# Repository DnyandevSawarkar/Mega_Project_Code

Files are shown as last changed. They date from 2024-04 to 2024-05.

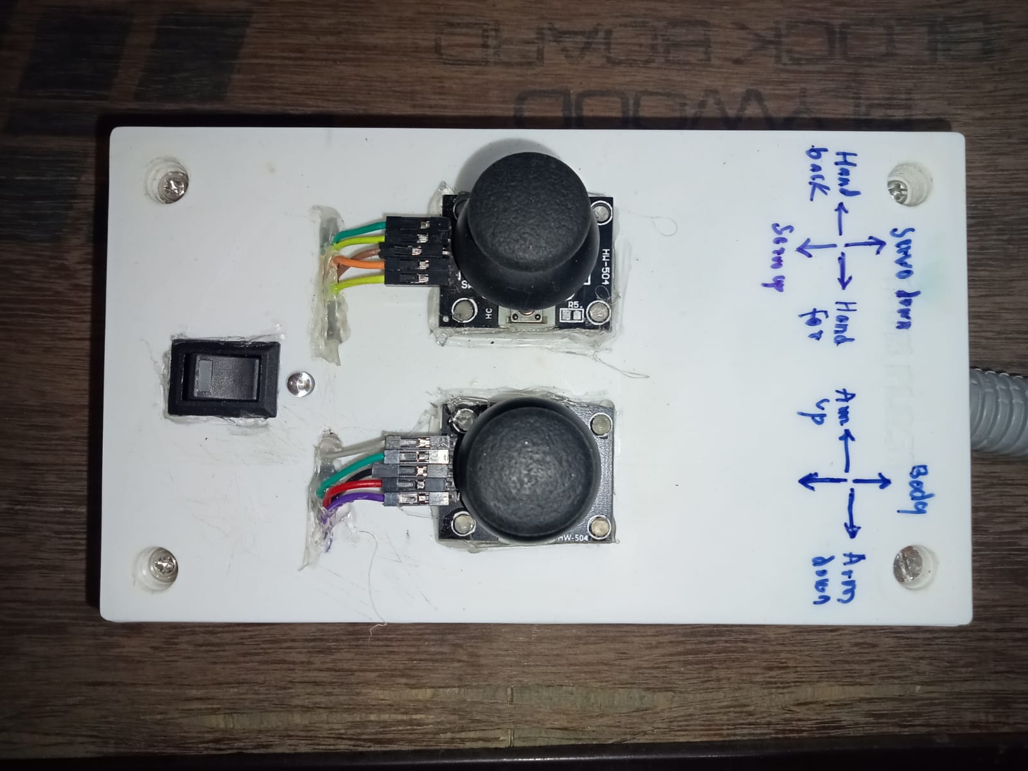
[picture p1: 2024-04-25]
Images/control_unit.jpg

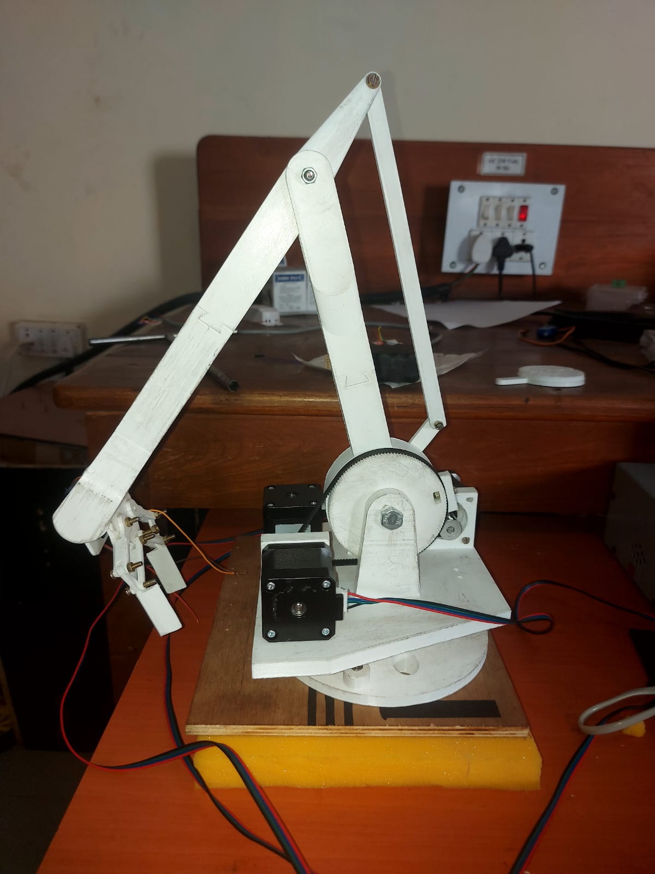
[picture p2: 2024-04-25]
Images/arm_right.jpg

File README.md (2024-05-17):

# Mega_Project_Code
# Name : Design and Development of Robotic ARM for Educational Purpose.
## Description
* Creating Platforms for Student having interest in Robotics or Cording.
* Platform to teach and demonstrate Ladder Coding.
* Controlling Robotic Arm using Joystick's to attract Small Class Student's.
## Information
➥ Application Creator:
 * icon.rc                      : Icon file path container for icon.res.
 * icon.res                     : Icon file for the application.
 * icon256x256.ico              : Icon file
 * Robotic Arm Controller.c     : Main C file of the application.
 * Robotic Arm Controller.exe   : Main executable file of the application.

➥ Backend:
 *    backend.py        : Get  data from the front end and send it to the esp-01 microcontroller.
 *    text.txt          : File that will be read by the esp-01, contains a block controller for the robotic arm.

➥ Body Parts STL:
 * STL Files Body and Gripper parts of the robotic arm.

➥ Frontend:
 *    index.html        : The main page of the website where you can write in an input field what command do you want to execute on the robotic arm.
 *    styles.css        : Stylesheet of the web page.
 *    script.js         : Functions related with the user interface (buttons,blocks,interconnecting link with backend.

➥ Mega Project ESP: 
 *    ESP-01 code to get the data sent by the backend and send it UNO for excutiong.
 *    Control Servo motors of Gripper according UNO feedbacks .
 *    Give feedback to UNO  about the execution status of gripper  movements.

➥ Mega Project UNO: 
 *    Uno Code to execute commands received from ESP.
 *    Controll Stepper Motor of required part.
 *    Send Command to ESP for execution Gripper Movements.
 *    Monitor Joystick and Robotic Arm.

➥ Py_Module_Installer:
 *    req.c            : C code which contains list of python module required for backend.
 *    req.exe          : Excutalbe exe file which will install all the required python module.

## Hardware Configuration
### UNO
* D12  : Joystick 1 Switch
* D11  : Joystick 1 Switch ( Z+ pin of CNC Shield)
* A0   : Joystick 1 Vx
* A1   : Joystick 1 Vy
* A2   : Joystick 2 Vx
* A3   : Joystick 2 Vy
* GND  : Joysticks GND
* 5V   : Joysticks VCC

### NodeMCU
* D4   : Servo 1 Signal (Gripper Body)
* D3   : Servo 2 Signal (Gripper Hands)
* GND  : Servos GND
* 5V   : Servos VCC

### Serial Communication
* UNO RX -> TX ESP
* ESP RX -> TX UNO

### Power Supply
* 230V AC to
   * 12V 5Amp. DC for CNC Shield
   * 9V 1.5Amp. DC for UNO Power Jack
      * 9V to 5V (7805) for NodeMCU Vin

➥ Note : Use separate power source for Joystcks and Servos for proper Working
* Servo 5V from 7805
* Joystick's 5V from CNC Shield 

## How To Run
* Download and Install [Python ](https://www.python.org/downloads/).
* Clone git repository.
* Install all the required python module using req.exe file.
* Power on Roboic Arm Control Unit
* Open Robotic Arm Controller.exe
* Connect System to NodeMCU Wi-Fi 
    * SSID : Robotic_Arm 
    * Password : Robotic_Arm.

## Testing
### 1) Software Application.
* Create Ladder Code to Controll Robotic Arm and Press Submite Button.
* Observe Robotic Arm Movement.

### 2) Hardware Application 
* Controll Robotic Arm by Using Joystick's. 

## Pictures
### Robotic Arm
Final_Arm

arm_right

arm_left

### Pick and Place operation 
pick_place

### Web Dashboard
Web Page

### Control Unit
control_unit

### Block Diagram 
Robotic arm block diagram

### FlowChart
#### Hardware - Joystick Control
joystick

#### Software - Web Dashboard Control
web_flowchart

### Circuit Schematic and PCB Board Connection
#### Schematic
circuit

#### Top Layer
Top_Layer

#### Buttom Layer
Bottom_layer

* Note : Circuit Schematic and PCB Board Connection are only for understanding connection their no need of this PCB CNC Shield get directly attached to UNO and for mounting NodeMCU we can create ZeroPCB based PCB which directly connects to CNC shield and works on external supply obtained from 7805 as an input for servo and NodeMCU

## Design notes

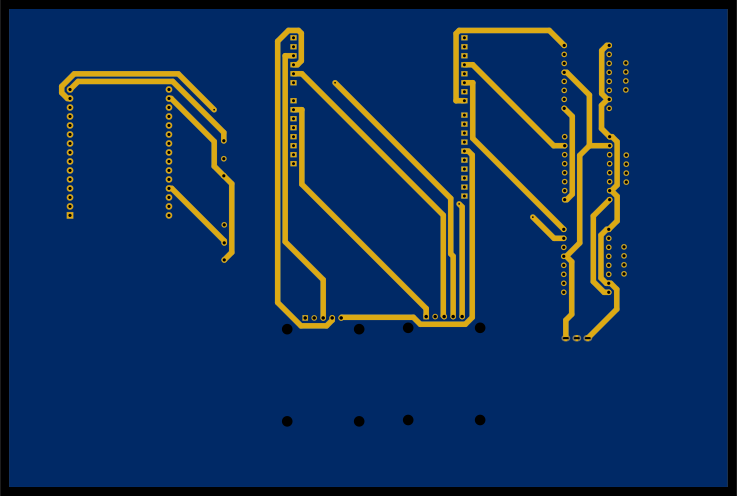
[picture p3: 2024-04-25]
Images/Bottom_layer.png

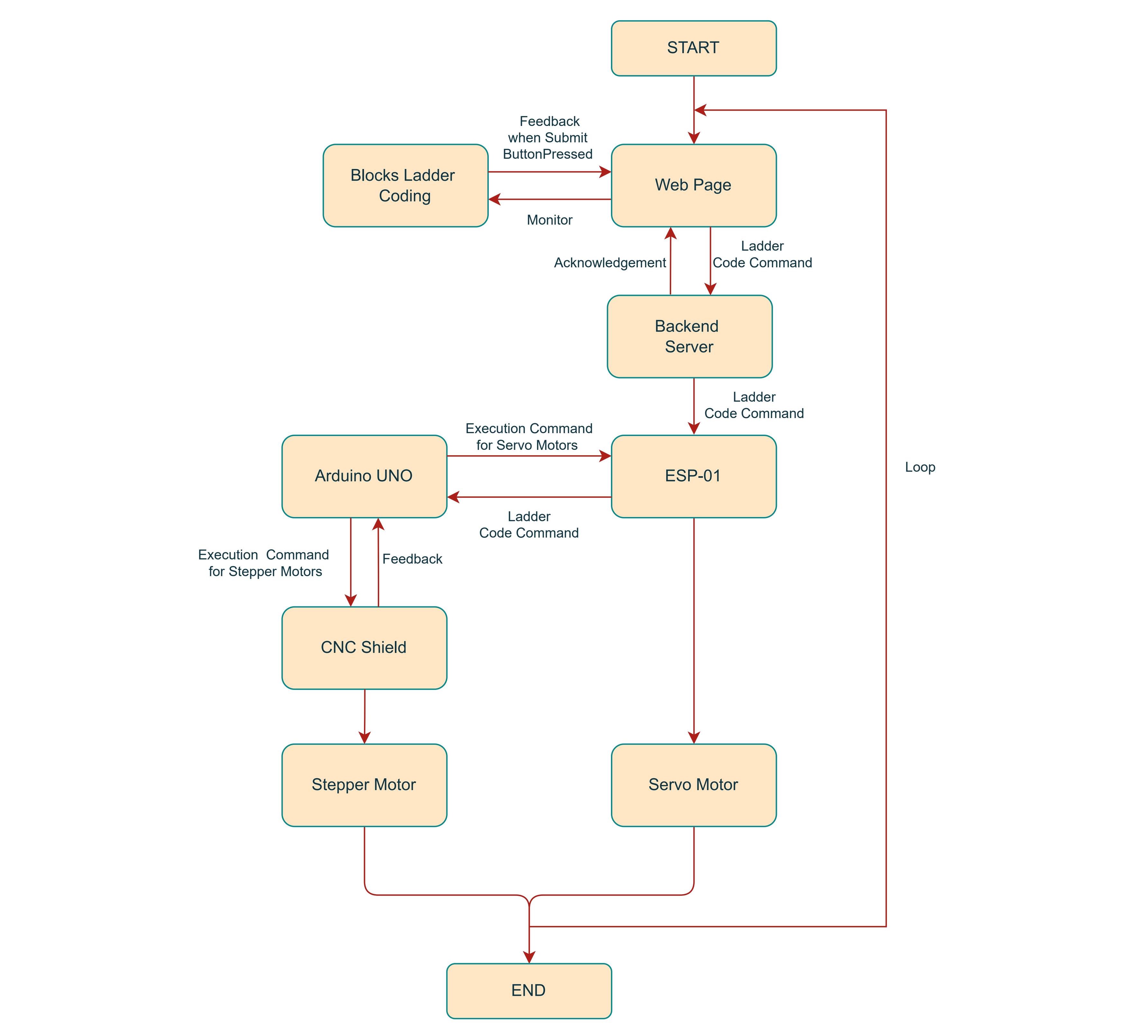
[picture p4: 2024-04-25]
Images/web_flowchart .jpg

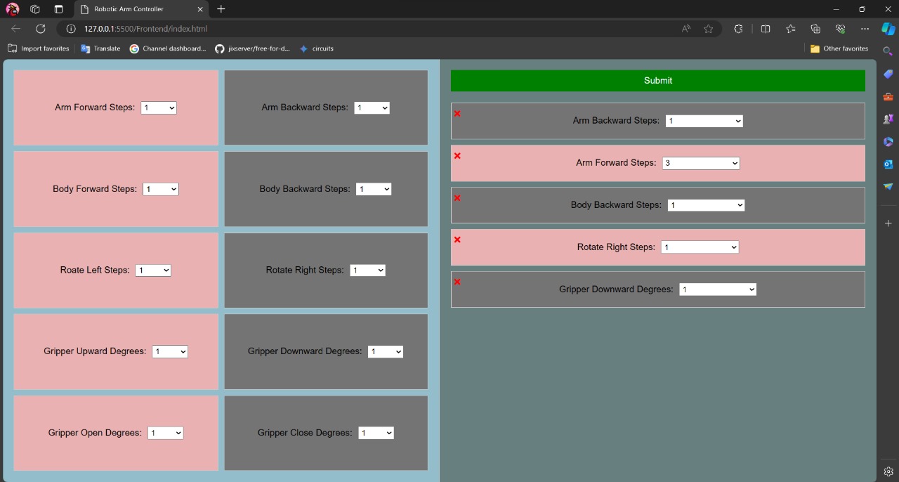
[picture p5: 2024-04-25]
Images/Web Page.jpg

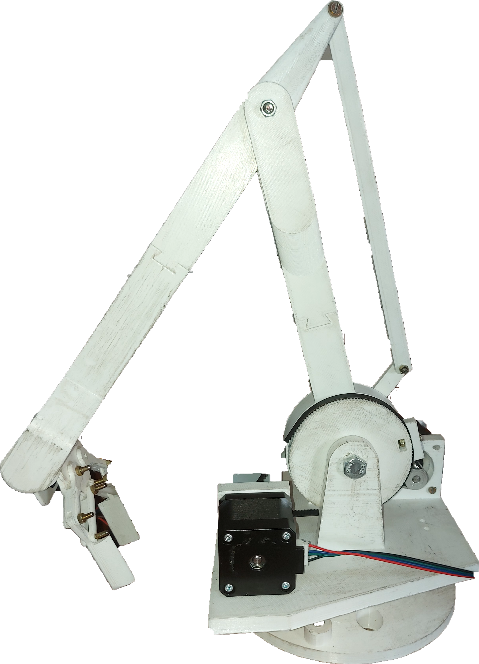
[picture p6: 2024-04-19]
Images/Final_Arm.png

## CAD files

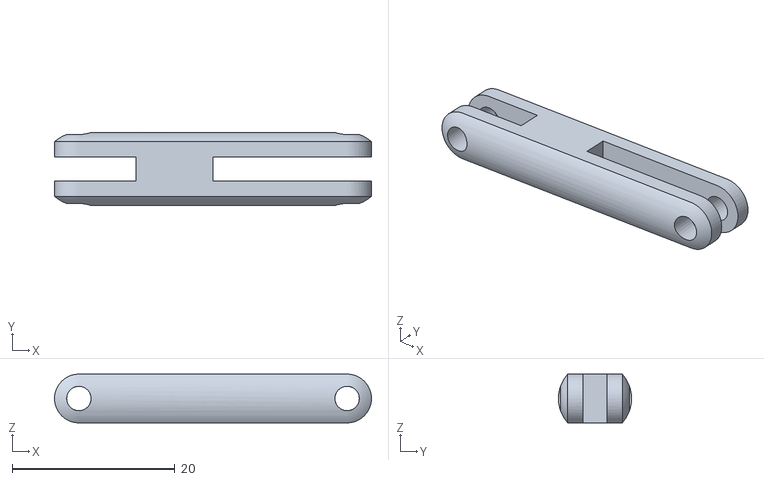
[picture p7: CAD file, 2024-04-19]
Body_Parts_STL/Phalange_medial (R).stl
39.0 x 9.00 x 6.00

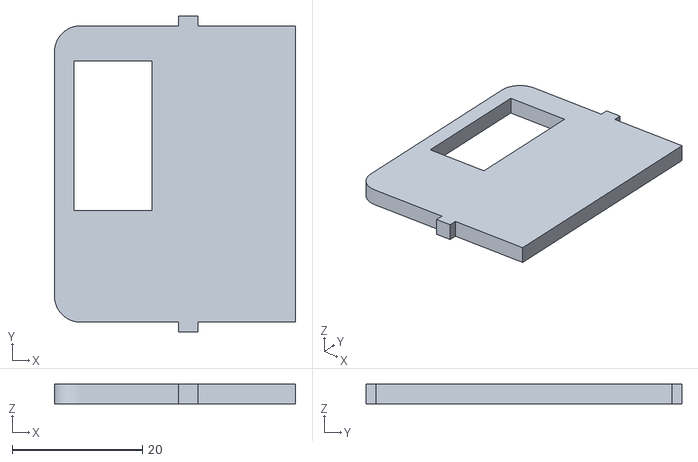
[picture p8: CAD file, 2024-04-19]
Body_Parts_STL/Arm_C1.stl
37.0 x 48.5 x 3.00

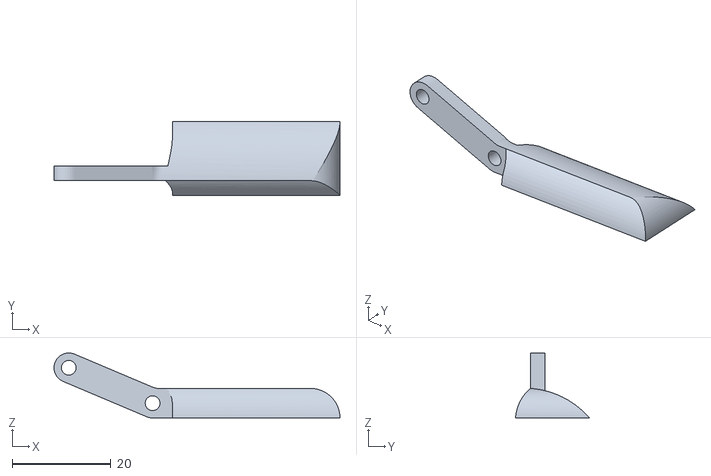
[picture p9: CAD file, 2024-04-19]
Body_Parts_STL/Phalange_distal_L.stl
58.0 x 15.0 x 13.2

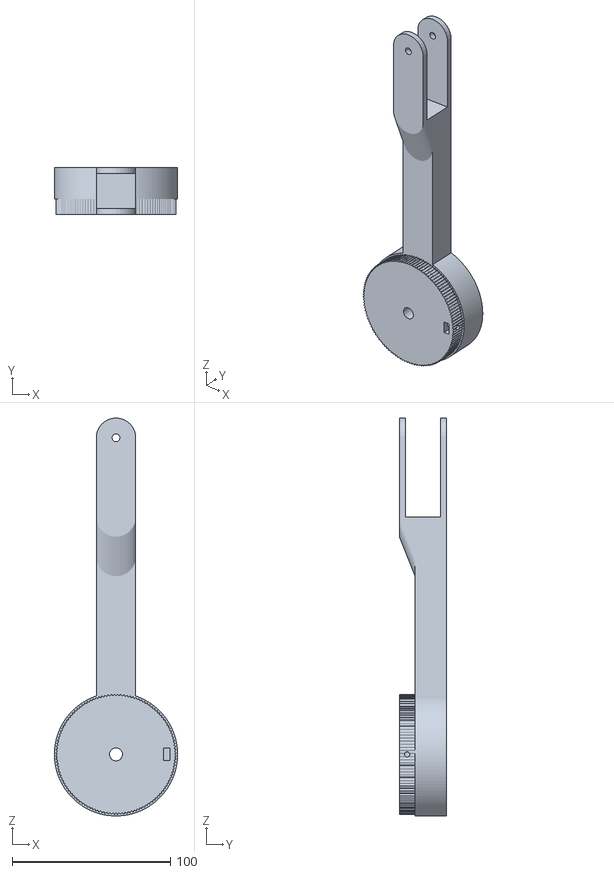
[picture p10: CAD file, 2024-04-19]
Body_Parts_STL/arm_2_with_pully.stl
77.9 x 30.0 x 251.4

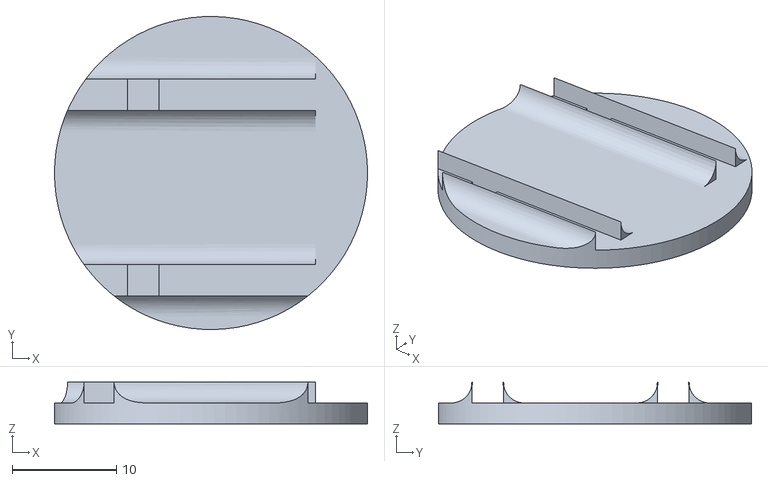
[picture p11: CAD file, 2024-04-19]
Body_Parts_STL/Arm_C3.stl
30.0 x 30.0 x 4.00

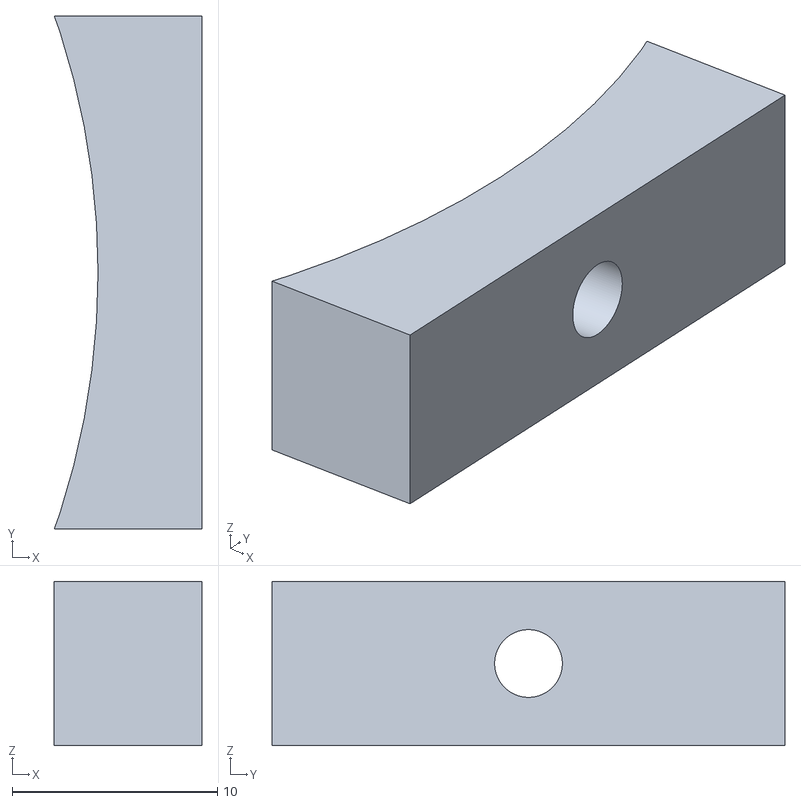
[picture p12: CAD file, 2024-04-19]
Body_Parts_STL/base_2_holder.stl
7.19 x 25.0 x 8.00

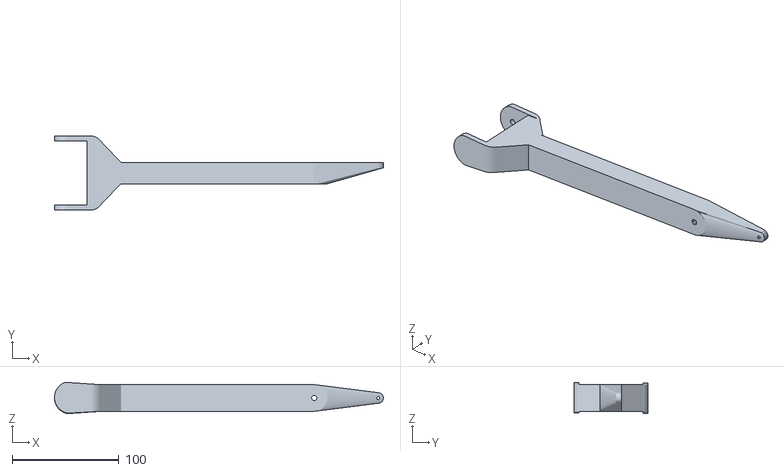
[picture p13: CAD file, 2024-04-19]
Body_Parts_STL/arm_1.stl
308.7 x 69.9 x 29.3

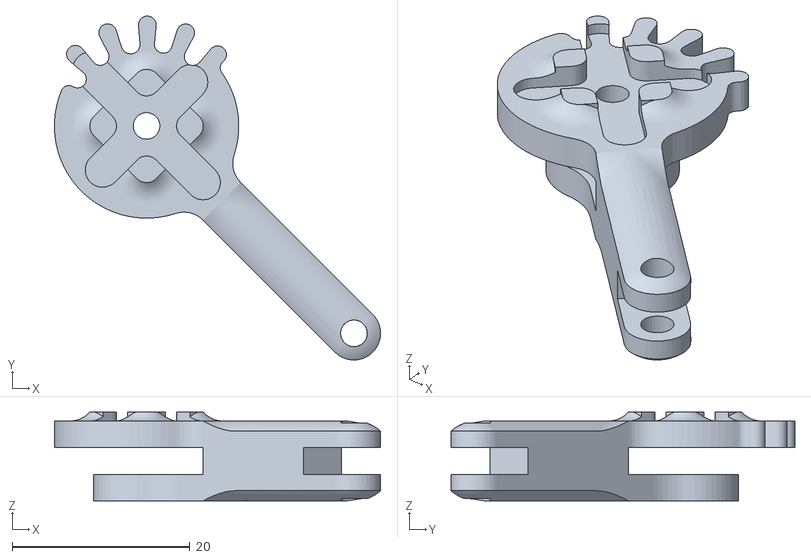
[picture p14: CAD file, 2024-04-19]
Body_Parts_STL/Phalnge_proximal_R.stl
36.7 x 38.7 x 10.0

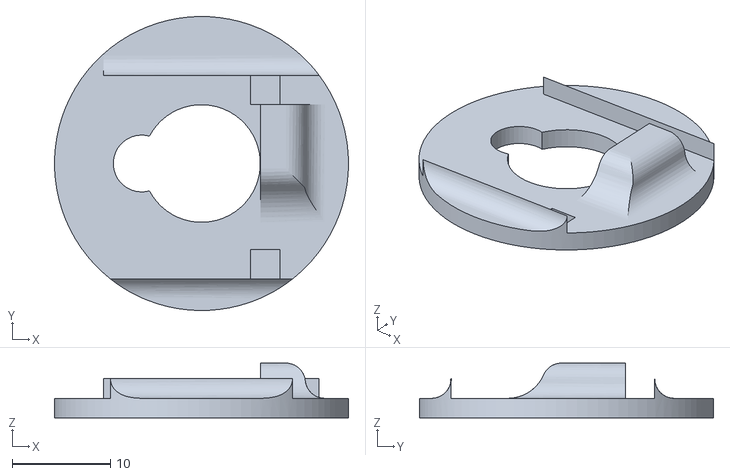
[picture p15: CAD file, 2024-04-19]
Body_Parts_STL/Arm_C4.stl
30.0 x 30.0 x 5.60

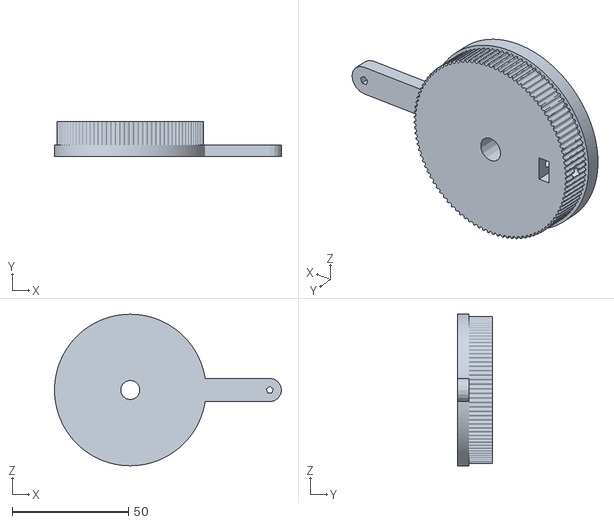
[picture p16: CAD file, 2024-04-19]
Body_Parts_STL/arm_1_pully.stl
97.6 x 15.0 x 65.2

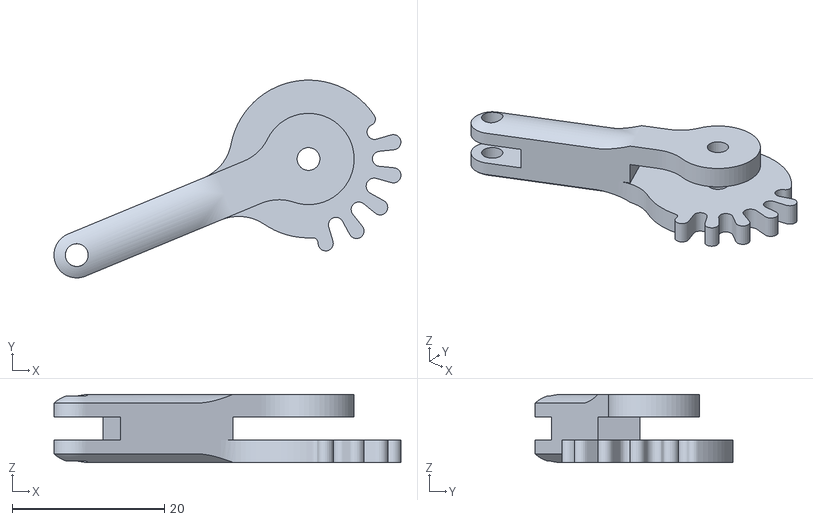
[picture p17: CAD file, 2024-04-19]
Body_Parts_STL/Phalange_proximal_L.stl
45.6 x 26.0 x 9.00

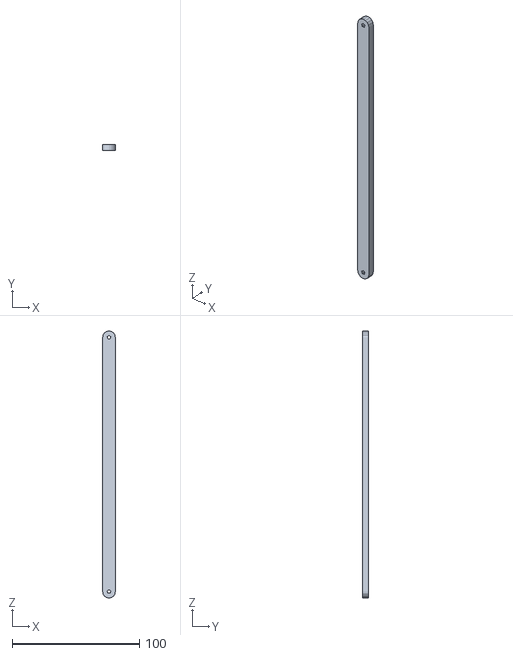
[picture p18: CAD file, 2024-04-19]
Body_Parts_STL/arm_1_rod.stl
10.0 x 5.00 x 210.0

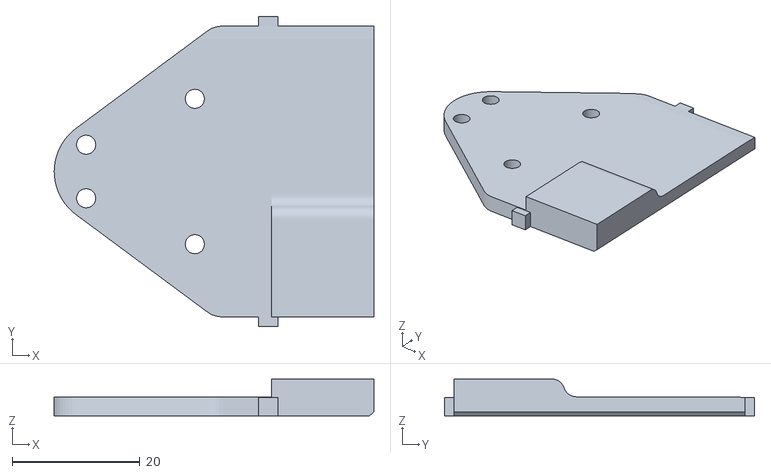
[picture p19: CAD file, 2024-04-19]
Body_Parts_STL/Arm_C2.stl
50.0 x 48.5 x 5.78

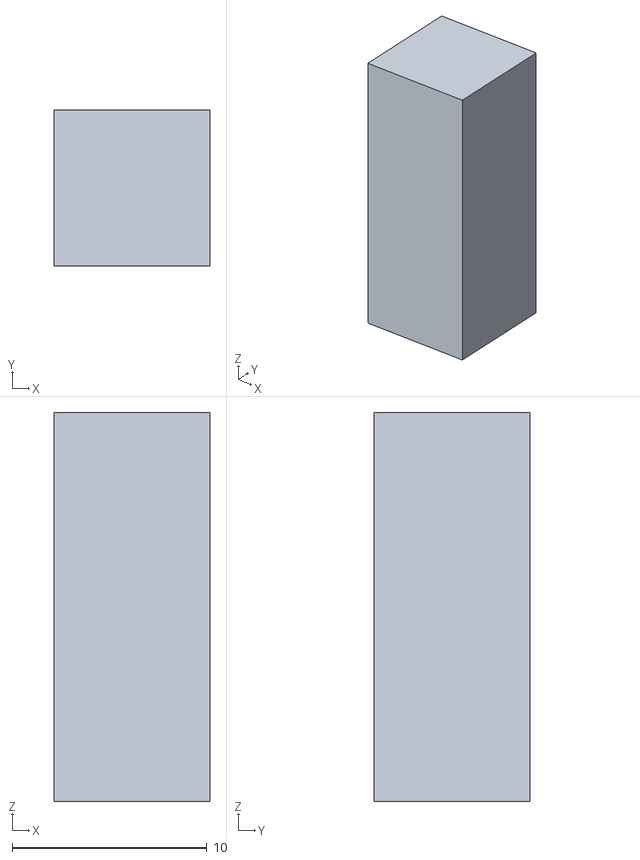
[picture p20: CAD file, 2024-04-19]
Body_Parts_STL/arm_1_holder.stl
8.00 x 8.00 x 20.0

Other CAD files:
Body_Parts_STL/Phalange_distal_R.stl
Body_Parts_STL/arm_2_holder.stl
Body_Parts_STL/base_1.stl
Body_Parts_STL/base_2.stl

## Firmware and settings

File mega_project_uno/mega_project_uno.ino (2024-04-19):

#include <AccelStepper.h>
const int JoyX = A0; // Analog pin of joystick for Body 
const int JoyS = A1; // Analog pin of joystick for Servo
const int JoyY = A2; // Analog pin of joystick for Arm
const int JoyZ = A3; // Analog pin of joystick for Base
const int deadzone = 30;
long receivedMMdistance = 0;
char receivedCommand;
bool newData, runallowed = false;
const int open_sw = 12;
const int close_sw = 11;
const unsigned long debounceDelay = 50;  
unsigned long lastDebounceTime = 0;
int openSwState = HIGH;                 
int closeSwState = HIGH;                 
int lastOpenSwState = HIGH;              
int lastCloseSwState = HIGH;  
int openSwReading, closeSwReading, joyXValue, joyYValue, joyZValue, JoySValue , X, Y, Z, S,previousSState,prv_i;
AccelStepper stepper_x(1, 2, 5);
AccelStepper stepper_y(1, 3, 6);
AccelStepper stepper_z(1, 4, 7);
void setup() {
  pinMode(open_sw, INPUT);
  pinMode(close_sw, INPUT);
  digitalWrite(open_sw, HIGH);
  digitalWrite(close_sw, HIGH);
  stepper_x.setMaxSpeed(100.0);
  stepper_y.setMaxSpeed(100);
  stepper_z.setMaxSpeed(100);
  stepper_x.setAcceleration(100);
  stepper_y.setAcceleration(100);
  stepper_z.setAcceleration(100);
  Serial.begin(9600);
}
/////////////////////////////////////////////////////////////
void body_forward() {
  runallowed = true;
  receivedMMdistance = 10;
  // Serial.println("S1"); 
  stepper_x.move(10); 
}
void body_backward() {
  runallowed = true;
  receivedMMdistance = 10;
  // Serial.println("S1`"); 
  stepper_x.move(-10); 
}
////////////////////////////////////////////////////////////
void arm_forward() {
  runallowed = true;
  receivedMMdistance = 10;
  // Serial.println("S2"); 
  stepper_y.move(10); 
}
void arm_backward() {
  runallowed = true;
  receivedMMdistance = 10;
  // Serial.println("S2`"); 
  stepper_y.move(-10); 
}
//////////////////////////////////////////////////////////
void rotate_left() {
  runallowed = true;
  receivedMMdistance = 10;
  // Serial.println("S3"); 
  stepper_z.move(10); 

}
void rotate_right() {
  runallowed = true;
  receivedMMdistance = 10;
  // Serial.println("S3`"); 
  stepper_z.move(-10); 
}
////////////////////////////////////////////////////////
void servo_up() {
  // Serial.println("SU"); 
  Serial.println('e');
}
void servo_down() {
  // Serial.println("SD"); 
  Serial.println('c');
}
//////////////////////////////////////////////////////
void servo_open() {
  // Serial.println("SO"); 
    Serial.println('d');
}
void servo_close() {
  // Serial.println("SC"); 
    Serial.println('p');
}
//////////////////////////////////////////////////////////////
void handleSwitch(int i) {
  
  if(i!=prv_i){
    if(i == 1){
      servo_open(); 
    }
    if (i == -1){
      servo_close();
    }
    prv_i=i;
  }
  
  return;
}

/////////////////////////////////////////////////////////////
void stop() {
  runallowed = false;
  stepper_x.setCurrentPosition(0); 
  stepper_y.setCurrentPosition(0);
  stepper_z.setCurrentPosition(0); 
  stepper_x.stop();
  stepper_y.stop();
  stepper_z.stop();
}
/////////////////////////////////////////////////////////////
void joystick() {
  openSwReading = digitalRead(open_sw);
  closeSwReading = digitalRead(close_sw);
  joyXValue = analogRead(JoyX);
  joyYValue = analogRead(JoyY);
  joyZValue = analogRead(JoyZ);
  JoySValue = analogRead(JoyS);
  delay(10);
  ///////////////////////////////////////////////
  if (millis() - lastDebounceTime > debounceDelay) {
    lastDebounceTime = millis();
    if (openSwReading != openSwState) {
      // Serial.println("ooooooO");
      openSwState = openSwReading;
      handleSwitch(1);
     
    }
    if (closeSwReading != closeSwState) {
      closeSwState = closeSwReading;
      handleSwitch(-1);
      // Serial.println("Ssssssssssss");
    }
    handleSwitch(0);
    // Serial.println("xxxxxxxxxxxxxxxxxx");
    
  }
  /////////////////////////////////////////////
  lastOpenSwState = openSwReading;
  lastCloseSwState = closeSwReading;
  ////////////////////////////////////////////
  if ((400 < joyXValue) && (joyXValue <= 600))
    X = 0;
  if ((601 <= joyXValue) && (joyXValue <= 1024))
    X = 1; 
  if ((0 <= joyXValue) && (joyXValue <= 399))
    X = -1;

  ///////////////************///////////////
  if ((400 < joyZValue) && (joyZValue <= 600))
    Z = 0;
  if ((601 <= joyZValue) && (joyZValue <= 1024))
    Z = 1; 
  if ((0 <= joyZValue) && (joyZValue <= 399))
    Z = -1;

  ///////////////************////////////////
  if ((400 < joyYValue) && (joyYValue <= 600))
    Y = 0;
  if ((601 <= joyYValue) && (joyYValue <= 1024))
    Y = -1; 
  if ((0 <= joyYValue) && (joyYValue <= 399))
    Y = 1;

  ///////////////************////////////////
  if ((400 < JoySValue) && (JoySValue <= 600))
    S = 0;
  if ((601 <= JoySValue) && (JoySValue <= 1024))
    S = -1; 
  if ((0 <= JoySValue) && (JoySValue <= 399))
    S = 1;

  ///////////////////////////////////////////
  // delay(500);
  if (X == 1){
    
    body_forward();
  }
  /////////////////////
  else if (X == -1)
    body_backward();
  /////////////////////
  else if (Y == 1)
    arm_forward();
  /////////////////////
  else if (Y == -1)
    arm_backward();
  /////////////////////
  else if (Z == 1)
    rotate_left();
  /////////////////////
  else if (Z == -1)
    rotate_right();
  ////////////////////
  else if (S != previousSState) {
    // Serial.println(previousSState);
    // Serial.println(S);
    if (S == 1) {
      servo_up(); // Call servo_up() if S changed from 0 to 1
    } else if (S == -1) {
      servo_down(); // Call servo_down() if S changed from 0 to -1
    }
    // Update previous state of S
    previousSState = S;
  }
  /////////////////////
  else
    stop(); 
}
////////////////////////////////////////////////////////
void checkSerial(){
  if (Serial.available() > 0) 
  {
    receivedCommand = Serial.read(); 
    newData = true; 
  }
  if(newData == true){
    /////////////////////////////////////////
    if(receivedCommand == 'q'){
      // Serial.println("S1"); 
      body_forward();
    }
    //////////////////
    if(receivedCommand == 'w'){
      // Serial.println("S1`"); 
      body_backward(); 
    }
    ////////////////////////////////////////////
    if(receivedCommand == 'a'){
      // Serial.println("S2"); 
      arm_forward();
    }
    //////////////////
    if(receivedCommand == 's'){
      // Serial.println("S2`"); 
      arm_backward();
    }
    //////////////////////////////////////////////
    if(receivedCommand == 'z'){
      // Serial.println("S3"); 
      rotate_left(); 
    }
    //////////////////
    if(receivedCommand == 'x'){
      // Serial.println("S3`"); 
      rotate_right();
    }
    ////////////////////////////////////////////
    if(receivedCommand == 'e'){
      servo_up();
    }
    //////////////////
    if(receivedCommand == 'c'){
      servo_down();
    }
    //////////////////////////////////////////
    if(receivedCommand == 'p'){
      servo_open();
    }
    //////////////////
    if(receivedCommand == 'd'){
      servo_close();
    }
    ////////////////////////////////////////
    if(receivedCommand == 'f'){
      Serial.println("STOP "); 
      stop();
    }
    ////////////////////////////////////////
  }
  newData = false;
}
//////////////////////////////////////////////////////////////
void continuousRun() 
{
  if (runallowed == true)
  {
    if ((abs(stepper_x.currentPosition()) < receivedMMdistance)||(abs(stepper_y.currentPosition()) < receivedMMdistance)||(abs(stepper_z.currentPosition()) < receivedMMdistance)) //abs() is needed because of the '<'
    {
      stepper_x.run(); 
      stepper_y.run();
      stepper_z.run();
    }
    else 
    {
      runallowed = false; 
    }
  }
  else
  {
    return;
  }
}
//////////////////////////////////////////////////////////////
void loop()
{
  checkSerial();
  continuousRun(); 
  joystick();
}

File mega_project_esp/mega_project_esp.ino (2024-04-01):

#include <ESP8266WiFi.h>
#include <ESP8266WebServer.h>
#include <Servo.h>
const char *ssid = "Robotic_Arm"; // SSID of the ESP-01 in SoftAP mode
const char *password = "Group#23"; // Password for the SoftAP mode
ESP8266WebServer server(80);
Servo myServo;
const int servoPin = 2; // D4
int servo_index = 0;
int servo_values[] = {10, 20, 35, 45, 55, 60, 75, 80, 95, 110, 120, 130, 145, 150};
int servo_values_count = sizeof(servo_values) / sizeof(servo_values[0]);
Servo myServo1;
const int servoPin1 = 0; // D3
int servo_index1 = 0;
int servo_values1[] = {55, 60, 65, 70, 75, 80, 95, 110, 120, 130, 145, 165, 175};
int servo_values1_count = sizeof(servo_values1) / sizeof(servo_values1[0]);
void setup() {
  Serial.begin(9600);
  delay(10);
  WiFi.softAP(ssid, password);
  server.on("/receive", HTTP_POST, handleReceive);
  server.begin();
  myServo.attach(servoPin);
  myServo.write(servo_values[servo_index]);
  myServo1.attach(servoPin1);
  myServo1.write(servo_values1[servo_index1]);
}

void loop() {
  server.handleClient();
  if (Serial.available() > 0) {
    char receivedCommand = Serial.read();
    // Serial.println(receivedCommand);
    if (receivedCommand == 'e') {
      Serial.println(" U");
      servo_up();
    }
    if (receivedCommand == 'c') {
      Serial.println(" D");
      servo_down();
    }
    if (receivedCommand == 'd') {
      Serial.println(" O");
      servo_open();
    }
    if (receivedCommand == 'p') {
      Serial.println(" B");
      servo_close();
    }
  }
}

void handleReceive() {
  if (server.hasArg("content")) {
    String content = server.arg("content");
    Serial.println(content);
  } else {
    Serial.println("NULL");
  }
  server.send(200, "text/plain", "Content received successfully.");
}

void servo_up() {
  if (servo_index < servo_values_count - 1) {
    servo_index++;
    servo_write(servo_values[servo_index]);
  } else {
    Serial.println("U L R");
  }
}

void servo_down() {
  if (servo_index > 0) {
    servo_index--;
    servo_write(servo_values[servo_index]);
  } else {
    Serial.println("L L R");
  }
}

void servo_write(int ang) {
  myServo.write(ang);
  Serial.println(ang);
}

void servo_open() {
  if (servo_index1 < servo_values1_count - 1) {
    servo_index1++;
    servo_write1(servo_values1[servo_index1]);
  } else {
    Serial.println("U L R");
  }
}

void servo_close() {
  if (servo_index1 > 0) {
    servo_index1--;
    servo_write1(servo_values1[servo_index1]);
  } else {
    Serial.println("L L R");
  }
}

void servo_write1(int ang) {
  myServo1.write(ang);
  Serial.println(ang);
}
